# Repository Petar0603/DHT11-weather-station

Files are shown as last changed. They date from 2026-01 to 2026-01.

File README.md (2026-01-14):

# DHT11-weather-station
Weather station with DHT11 sensor, PCB is made in KiCad 9.0 and STM32 microcontroller code is for Arduino IDE.

---
## About
DHT11 sensor is temperature and humidity sensor, it's output is presented on an SSD1306 OLED display.
Power supply circuit is based on MB102 protoboard power supply, it is used for 3.3V stable output.
STM32F103C8T6 microcontroller is used, programming is done via SWD (Serial Wire Debug).

---
## PCB
For PCB, libraries for DHT11 and 32.768kHz crystal oscillator needed to be made in KiCad.
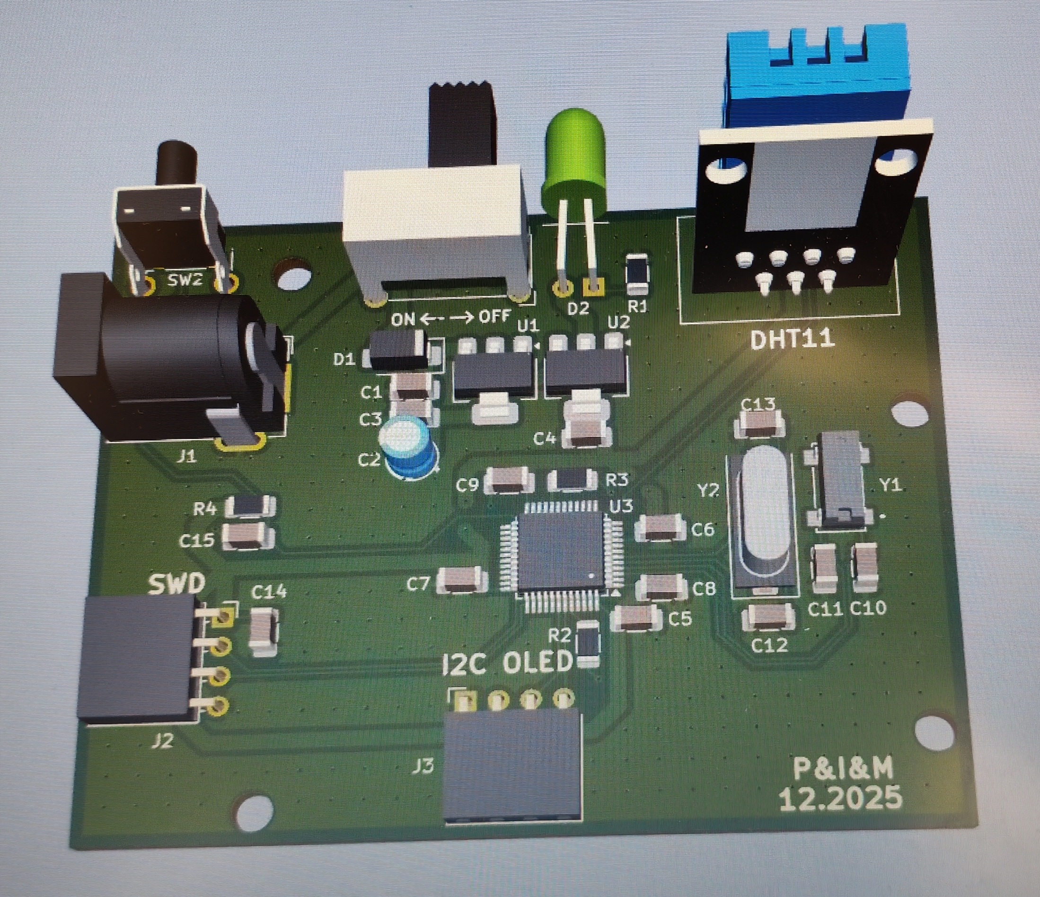
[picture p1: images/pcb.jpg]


---
## Prototype
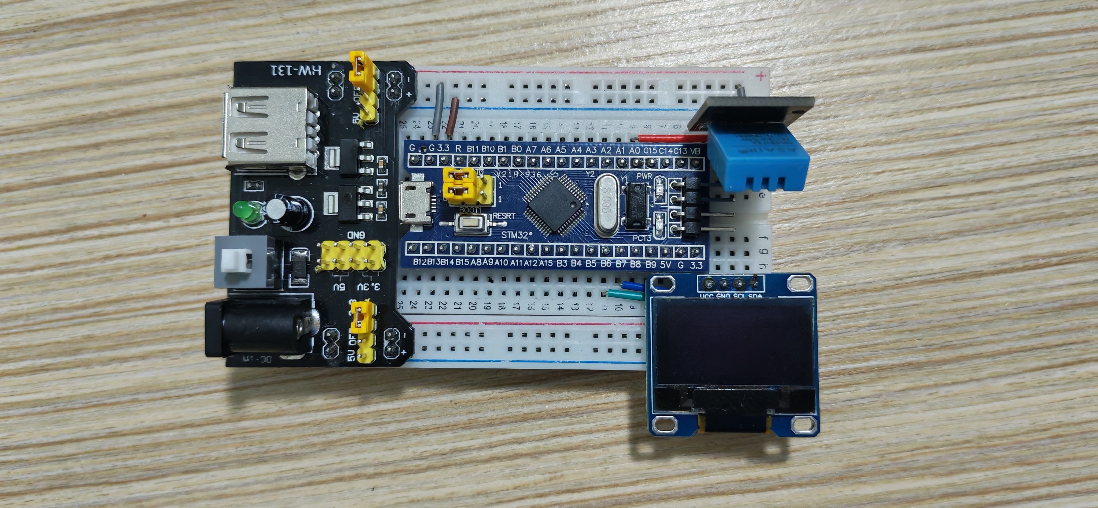
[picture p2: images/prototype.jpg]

A more detailed look on connections on the protoboard.
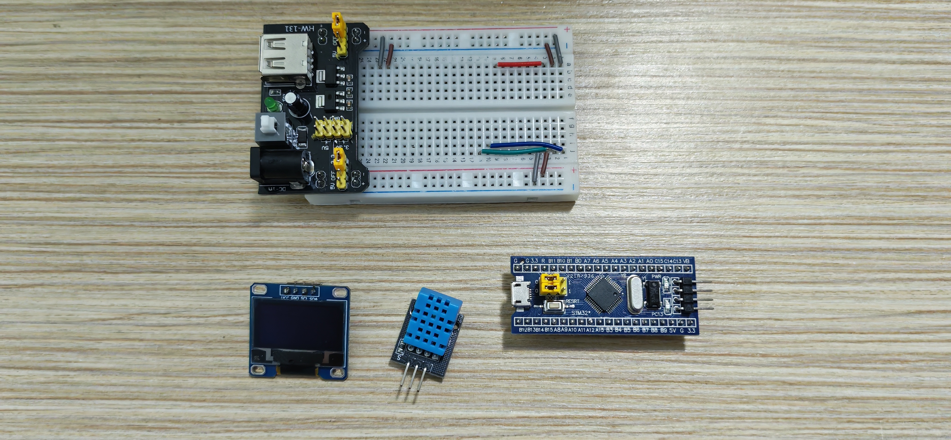
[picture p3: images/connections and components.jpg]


---

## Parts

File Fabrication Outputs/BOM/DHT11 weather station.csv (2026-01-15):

Reference | Qty | Value | DNP | Exclude from BOM | Exclude from Board | Footprint | Datasheet
C1,C3,C4,C5,C6,C7,C8,C9,C14,C15 | 10 | 100nF |  |  |  | Capacitor_SMD:C_1206_3216Metric | ~
C2 | 1 | 100uF |  |  |  | Capacitor_THT:CP_Radial_D4.0mm_P2.00mm | ~
C10,C11,C12,C13 | 4 | 20pF |  |  |  | Capacitor_SMD:C_1206_3216Metric | ~
D1 | 1 | 1N4007 |  |  |  | Diode_SMD:D_SMA | ~
D2 | 1 | LED |  |  |  | LED_THT:LED_D5.0mm_Horizontal_O6.35mm_Z3.0mm | ~
H1,H2,H3,H4 | 4 | MountingHole |  | Excluded from BOM |  | MountingHole:MountingHole_3.2mm_M3 | ~
J1 | 1 | DC adapter input |  |  |  | Connector_BarrelJack:BarrelJack_GCT_DCJ200-10-A_Horizontal | ~
J2 | 1 | SWD sockets |  |  |  | Connector_PinSocket_2.54mm:PinSocket_1x04_P2.54mm_Horizontal | ~
J3 | 1 | SSD1306 OLED sockets |  |  |  | Connector_PinSocket_2.54mm:PinSocket_1x04_P2.54mm_Horizontal | ~
J4 | 1 | DHT11 sockets |  |  |  | DHT11 sensor:DHT11 | ~
R1 | 1 | 470 |  |  |  | Resistor_SMD:R_1206_3216Metric | ~
R2,R3 | 2 | 100k |  |  |  | Resistor_SMD:R_1206_3216Metric | ~
R4 | 1 | 10k |  |  |  | Resistor_SMD:R_1206_3216Metric | ~
SW1 | 1 | Power ON switch |  |  |  | Button_Switch_THT:SW_E-Switch_EG1224_SPDT_Angled | ~
SW2 | 1 | Reset switch |  |  |  | Button_Switch_THT:SW_Tactile_SPST_Angled_PTS645Vx83-2LFS | ~
U1 | 1 | AMS1117-5.0 |  |  |  | Package_TO_SOT_SMD:SOT-223-3_TabPin2 | http://www.advanced-monolithic.com/pdf/ds1117.pdf
U2 | 1 | AMS1117-3.3 |  |  |  | Package_TO_SOT_SMD:SOT-223-3_TabPin2 | http://www.advanced-monolithic.com/pdf/ds1117.pdf
U3 | 1 | STM32F103C8T6 |  |  |  | Package_QFP:LQFP-48_7x7mm_P0.5mm | https://www.st.com/resource/en/datasheet/stm32f103c8.pdf
Y1 | 1 | 32.768kHz |  |  |  | Blue Pill 32.768kHz 4 pin oscillator:XTAL_MC-306_32.7680K-G0_ROHS | ~
Y2 | 1 | 8MHz |  |  |  | Crystal:Crystal_SMD_HC49-SD | ~
 | 4 | M3 self tapping screws |  |  | Exclude from Board
 | 4 | male-female jumper wires |  |  | Exclude from Board

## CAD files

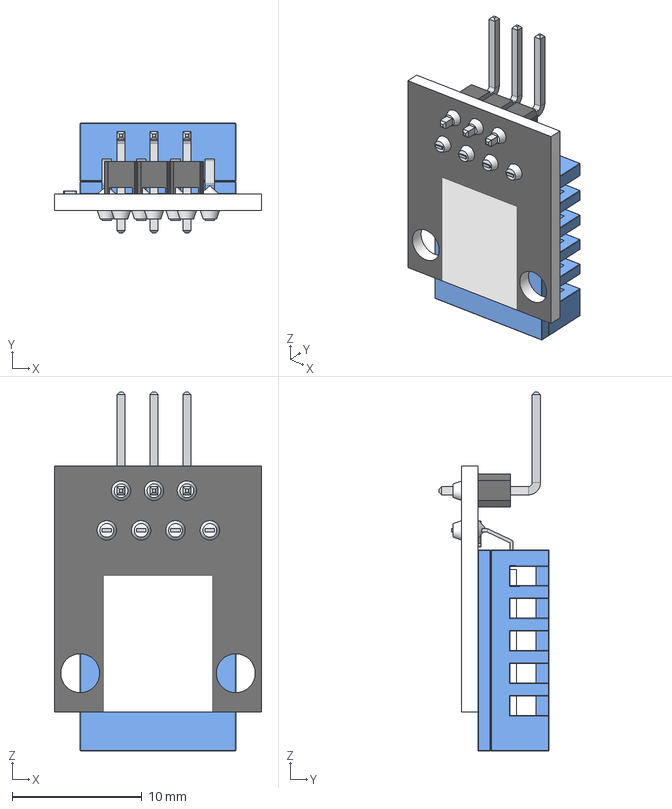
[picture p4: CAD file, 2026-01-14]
DHT11/DHT11.step
16.0 x 8.50 x 27.7 mm

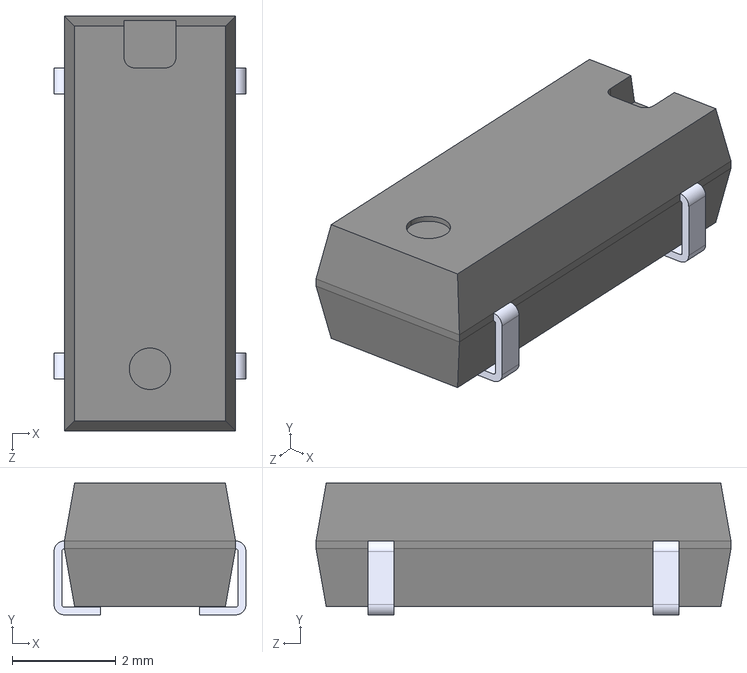
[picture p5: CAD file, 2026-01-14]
MC-306_32.7680K-G0_ROHS/MC-306_32.7680K-G0_ROHS.step
3.70 x 2.54 x 8.00 mm

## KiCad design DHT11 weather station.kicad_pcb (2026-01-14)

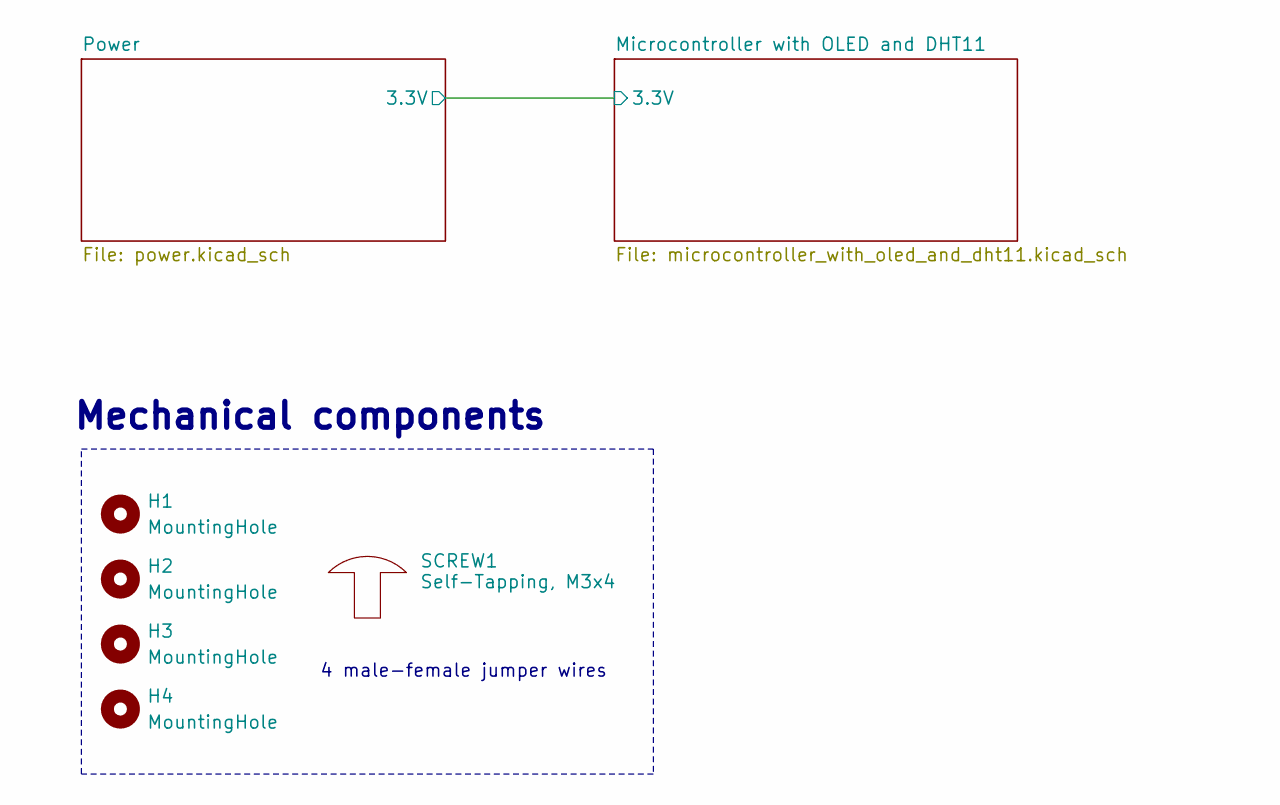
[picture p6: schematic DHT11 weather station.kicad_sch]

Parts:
H1, H2, H3, H4: MountingHole; MountingHole_3.2mm_M3
SCREW1: Self-Tapping, M3x4; Farnell 1420120

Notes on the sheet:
Mechanical components
4 male-female jumper wires

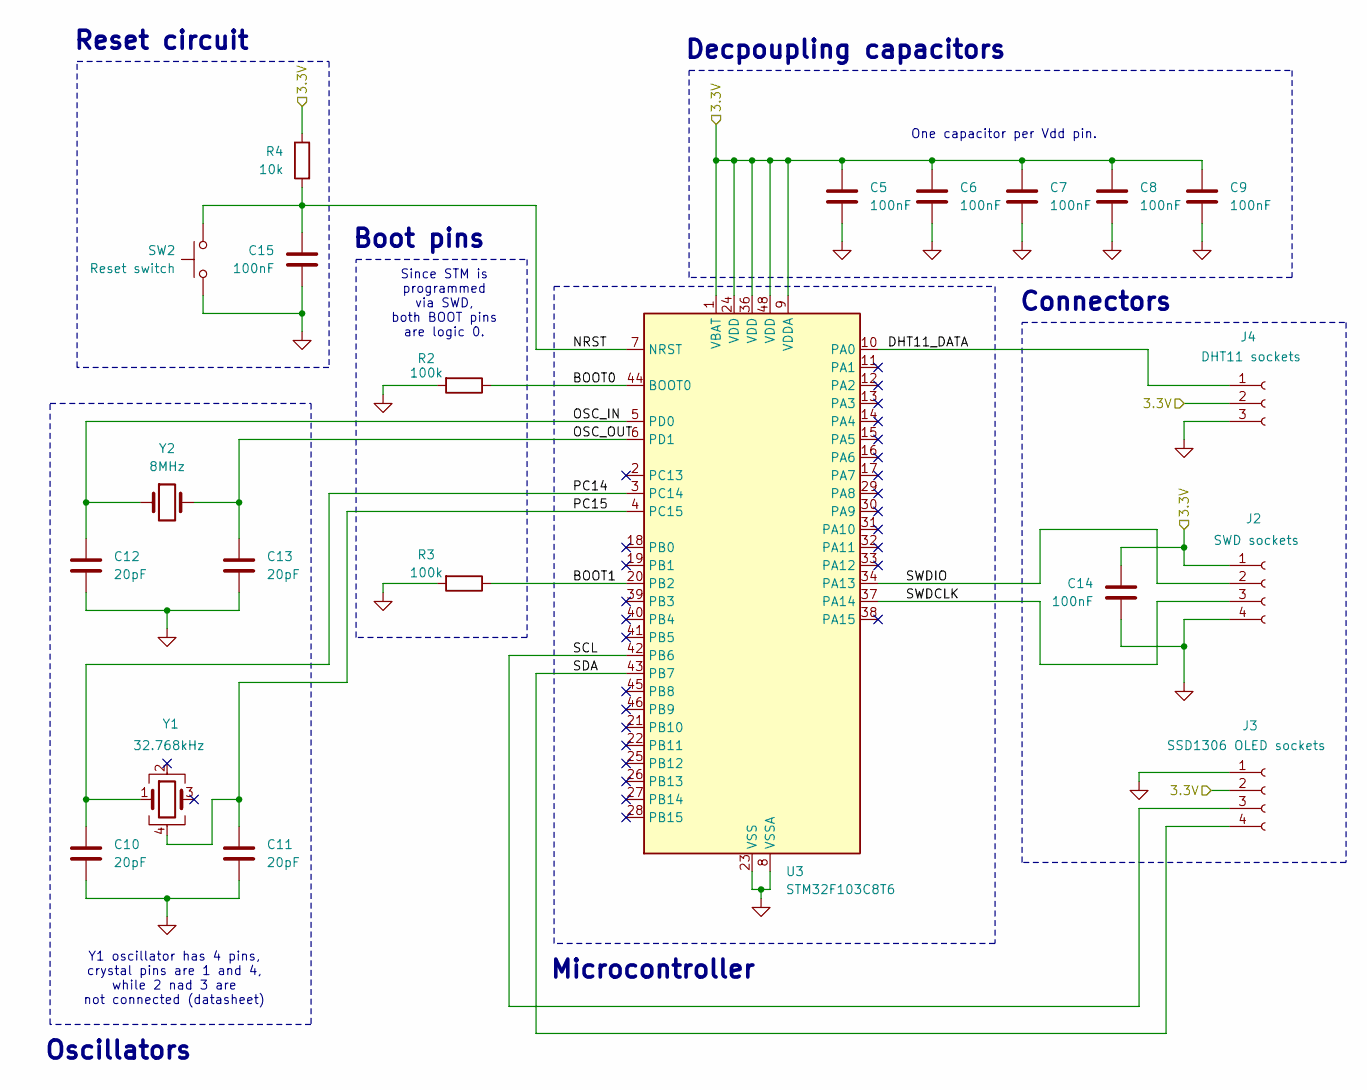
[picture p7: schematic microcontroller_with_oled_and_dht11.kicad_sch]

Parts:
C5, C6, C7, C8, C9, C14, C15: 100nF; C_1206_3216Metric
C10, C11, C12, C13: 20pF; C_1206_3216Metric
J2: SWD sockets; PinSocket_1x04_P2.54mm_Horizontal
J3: SSD1306 OLED sockets; PinSocket_1x04_P2.54mm_Horizontal
J4: DHT11 sockets; DHT11
R2, R3: 100k; R_1206_3216Metric
R4: 10k; R_1206_3216Metric
SW2: Reset switch; SW_Tactile_SPST_Angled_PTS645Vx83-2LFS
U3: STM32F103C8T6; LQFP-48_7x7mm_P0.5mm
Y1: 32.768kHz; XTAL_MC-306_32.7680K-G0_ROHS
Y2: 8MHz; Crystal_SMD_HC49-SD

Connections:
/Microcontroller with OLED and DHT11/3.3V: C5.1, C6.1, C7.1, C8.1, C9.1, C14.1, J2.1, J3.2, J4.2, R4.1, U3.1 (VBAT), U3.9 (VDDA), U3.24 (VDD), U3.36 (VDD), U3.48 (VDD); also elsewhere on the board
/Microcontroller with OLED and DHT11/BOOT0: R2.1, U3.44 (BOOT0)
/Microcontroller with OLED and DHT11/BOOT1: R3.1, U3.20 (PB2)
/Microcontroller with OLED and DHT11/DHT11_DATA: J4.1, U3.10 (PA0)
/Microcontroller with OLED and DHT11/NRST: C15.1, R4.2, SW2.1, U3.7 (NRST)
/Microcontroller with OLED and DHT11/OSC_IN: C12.1, U3.5 (PD0), Y2.1
/Microcontroller with OLED and DHT11/OSC_OUT: C13.1, U3.6 (PD1), Y2.2
/Microcontroller with OLED and DHT11/PC14: C10.1, U3.3 (PC14), Y1.1
/Microcontroller with OLED and DHT11/PC15: C11.1, U3.4 (PC15), Y1.4
/Microcontroller with OLED and DHT11/SCL: J3.3, U3.42 (PB6)
/Microcontroller with OLED and DHT11/SDA: J3.4, U3.43 (PB7)
/Microcontroller with OLED and DHT11/SWDCLK: J2.3, U3.37 (PA14)
/Microcontroller with OLED and DHT11/SWDIO: J2.2, U3.34 (PA13)
GND: C5.2, C6.2, C7.2, C8.2, C9.2, C10.2, C11.2, C12.2, C13.2, C14.2, C15.2, J2.4, J3.1, J4.3, R2.2, R3.2, SW2.2, U3.8 (VSSA), U3.23 (VSS), U3.35 (VSS), U3.47 (VSS); also elsewhere on the board

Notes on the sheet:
One capacitor per Vdd pin.
Y1 oscillator has 4 pins, crystal pins are 1 and 4, while 2 nad 3 are not connected (datasheet)
Oscillators
Boot pins
Reset circuit
Microcontroller
Connectors
Decpoupling capacitors
Since STM is programmed via SWD, both BOOT pins are logic 0.

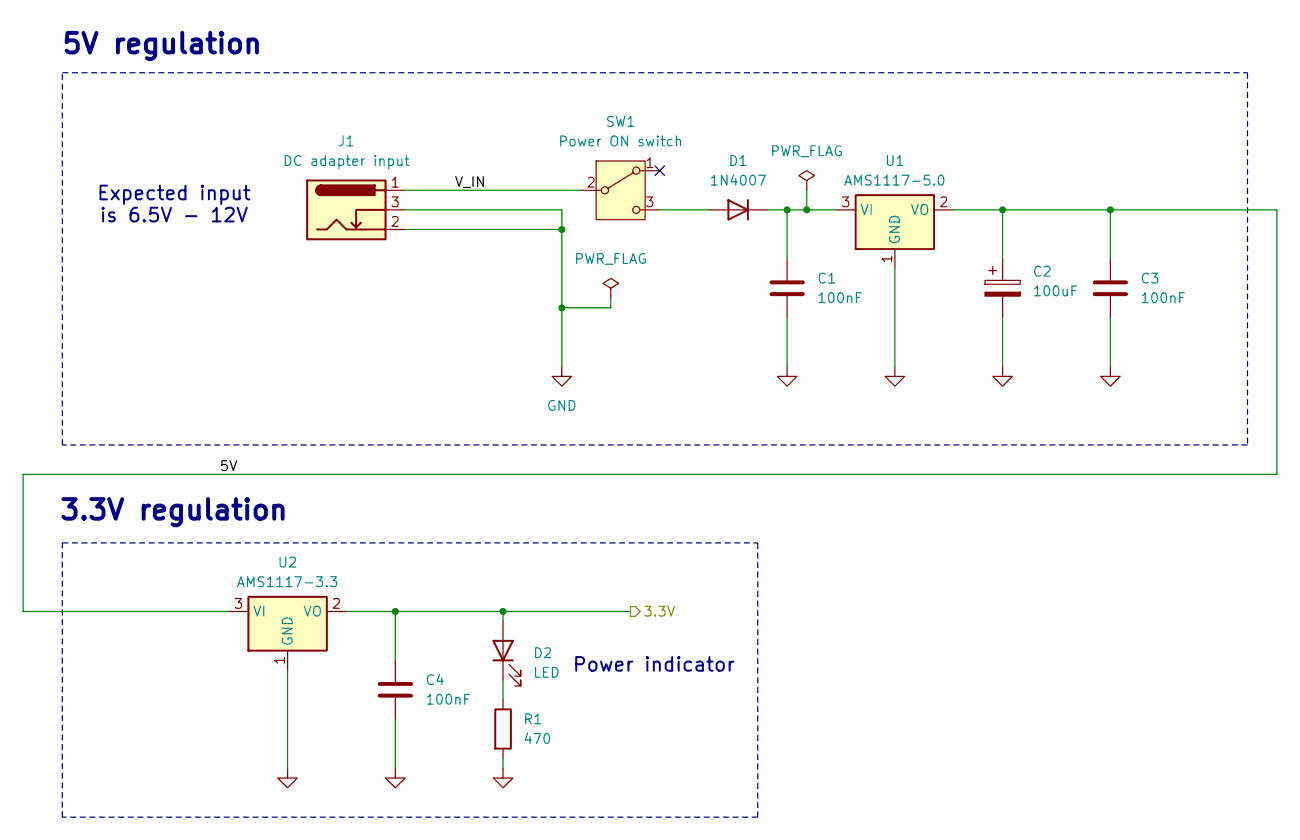
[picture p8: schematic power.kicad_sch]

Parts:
C1, C3, C4: 100nF; C_1206_3216Metric
C2: 100uF; CP_Radial_D4.0mm_P2.00mm
D1: 1N4007; D_SMA
D2: LED; LED_D5.0mm_Horizontal_O6.35mm_Z3.0mm
J1: DC adapter input; BarrelJack_GCT_DCJ200-10-A_Horizontal
R1: 470; R_1206_3216Metric
SW1: Power ON switch; SW_E-Switch_EG1224_SPDT_Angled
U1: AMS1117-5.0; SOT-223-3_TabPin2
U2: AMS1117-3.3; SOT-223-3_TabPin2

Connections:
/Microcontroller with OLED and DHT11/3.3V: C4.1, D2.2 (A), U2.2 (VO); also elsewhere on the board
/Power/5V: C2.1, C3.1, U1.2 (VO), U2.3 (VI)
/Power/V_IN: J1.1, SW1.2 (B)
GND: C1.2, C2.2, C3.2, C4.2, J1.2, J1.3, R1.2, U1.1 (GND), U2.1 (GND); also elsewhere on the board
unnamed: D1.2 (A), SW1.3 (C)
unnamed: C1.1, D1.1 (K), U1.3 (VI)
unnamed: D2.1 (K), R1.1

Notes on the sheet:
5V regulation
Power indicator
3.3V regulation
Expected input is 6.5V - 12V

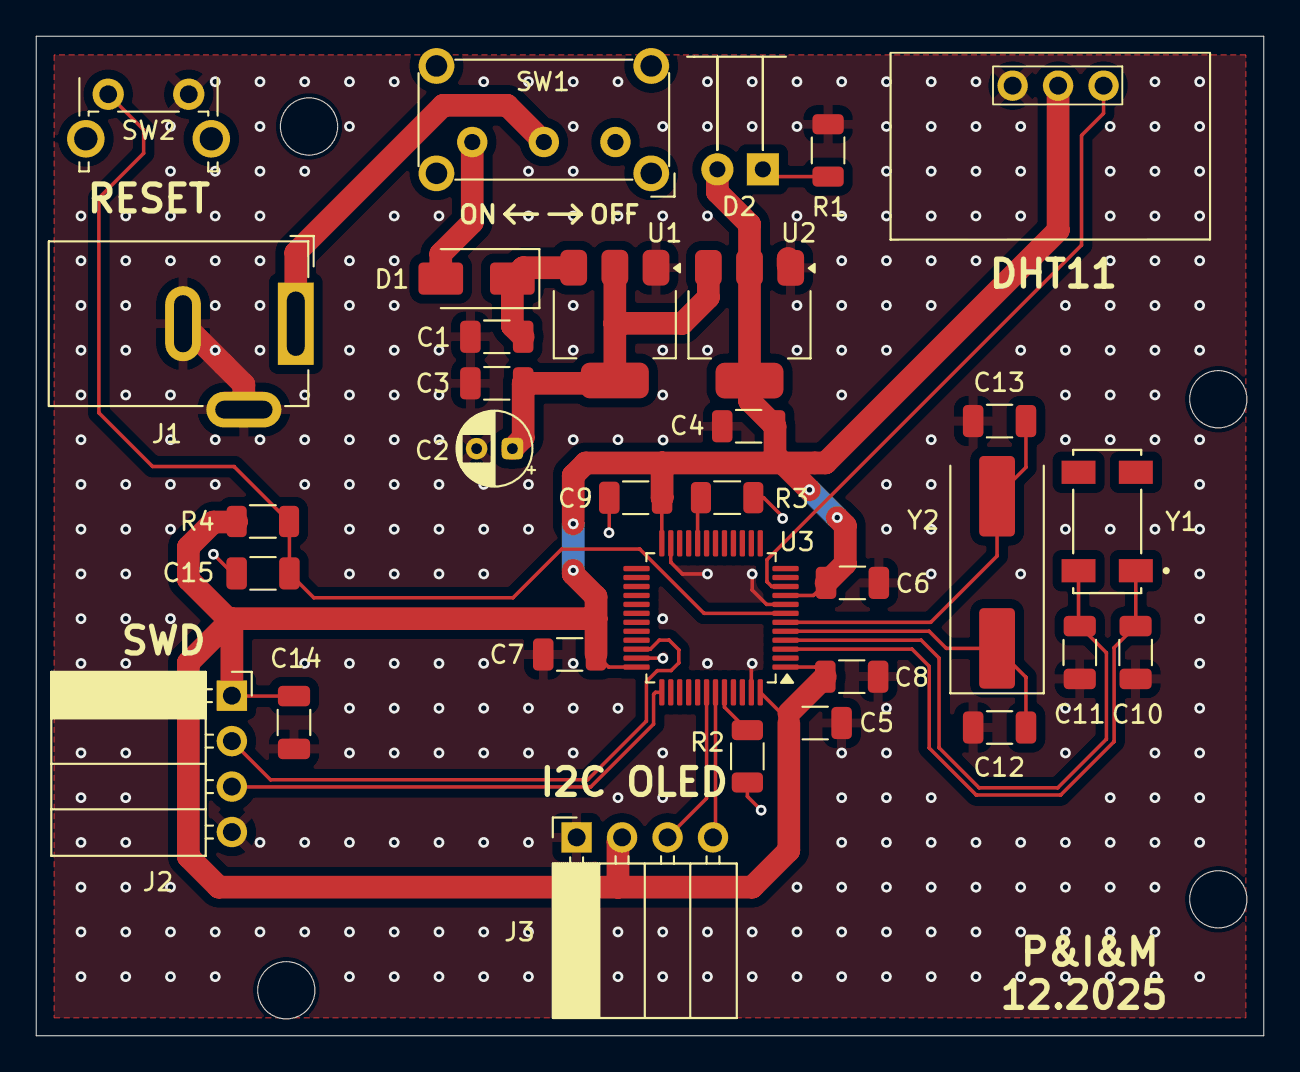
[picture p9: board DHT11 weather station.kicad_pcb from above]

Board: 2 copper layers, 68.6 x 55.8 mm, 36 parts (0 on the bottom side), 19 nets.

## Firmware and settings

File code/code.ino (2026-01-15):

#include <Arduino.h>
#include <Wire.h>
#include <Adafruit_GFX.h>
#include <Adafruit_SSD1306.h>
#include <DHT.h>

// PIN CONFIGURATION
#define DHTPIN PA0       // DHT11 DATA pin
#define DHTTYPE DHT11    // Sensor type
#define SCREEN_WIDTH 128
#define SCREEN_HEIGHT 64

DHT dht(DHTPIN, DHTTYPE);
Adafruit_SSD1306 display(SCREEN_WIDTH, SCREEN_HEIGHT, &Wire, -1);

void setup() {
  Serial.begin(115200);

  dht.begin();
  delay(1000);

  if (!display.begin(SSD1306_SWITCHCAPVCC, 0x3C)) {
    Serial.println("SSD1306 not found!");
    while (1);
  }
  
  display.clearDisplay();
  display.setTextSize(1);
  display.setTextColor(SSD1306_WHITE);
  display.setCursor(0, 0);
  display.println("DHT11 + OLED");
  display.println("STM32 Blue Pill");
  display.display();
  delay(2000);
}

void loop() {

  float h = dht.readHumidity();
  float t = dht.readTemperature();

  // Check if reading failed
  if (isnan(h) || isnan(t)) {
    Serial.println("Failed to read from DHT!");
    display.clearDisplay();
    display.setCursor(0, 0);
    display.println("DHT11 ERROR!");
    display.display();
    delay(2000);
    return;
  }

  Serial.print("Temp: ");
  Serial.print(t);
  Serial.print(" °C  Humidity: ");
  Serial.print(h);
  Serial.println(" %");

  display.clearDisplay();
  display.setTextSize(2);

  display.setCursor(0, 0);
  display.print("T: ");
  display.print(t, 1);
  display.print("C");

  display.setCursor(0, 30);
  display.print("H: ");
  display.print(h, 1);
  display.print("%");

  display.display();
  
  delay(2000);
}

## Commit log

2026-01-15 Removed screw symbol from schematic and added it to BOM along with jumper wires commit
    [DHT11 weather station.csv, DHT11 weather station.kicad_sch]
2026-01-15 Added the new scheamtic file
    [DHT11 weather station.kicad_sch]
2026-01-15 Added the step model for housing commit
